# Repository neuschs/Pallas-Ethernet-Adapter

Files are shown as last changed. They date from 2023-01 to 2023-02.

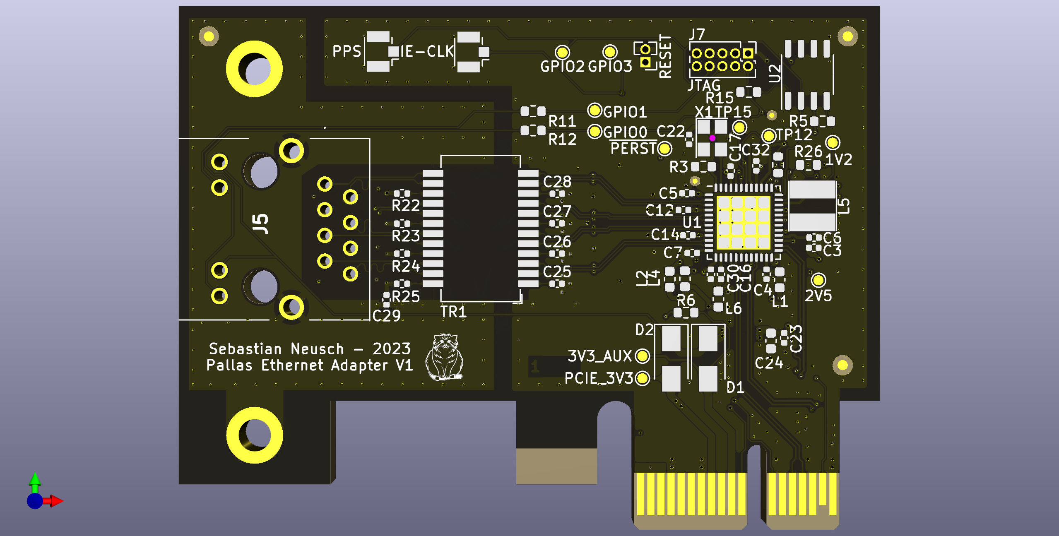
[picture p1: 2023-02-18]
documentation/pallas-ethernet-adapter_top.png

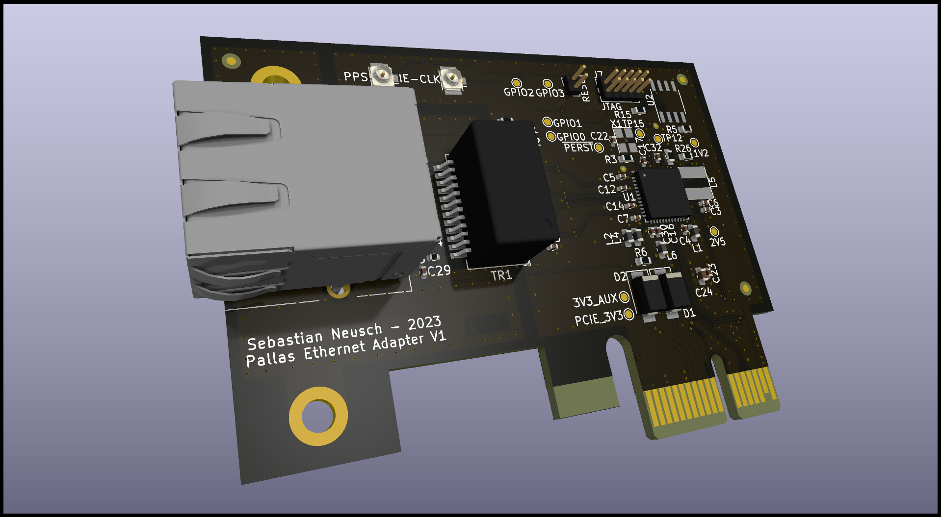
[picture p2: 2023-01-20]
documentation/pallas-ethernet-adapter.png

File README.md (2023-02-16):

# Pallas-Ethernet-Adapter
Open source PCIe ethernet adapter based on LAN7430

More information can be found on my blog: https://sebis-workshop.de/uncategorized/pallas-ethernet-adapter/

# Ordering and production parameters
So far I've just ordered the PCBAs and waiting to test my prototypes.
In the folder jlcpcb are the files from this KiCAD plugin located:
https://github.com/Bouni/kicad-jlcpcb-tools

Including position correction for some parts so the pick'n'place file is correct (please check before usage).

# Credits
Thanks to the KiCAD PCIe template project:
https://github.com/lucanastasio/PCIexpress-KiCad

# License
All datasheets are just for documentational pruposes here. All credits go to the companys which distributed them initially.

The Logo - the Pallas Cat - may not be redistributed, made public elsewhere or modified and is property of the author. 

This describes Open Hardware and is licensed under the CERN OHL v.1.2.
You may redistribute and modify this under the terms of the CERN OHL v.1.2. (http://ohwr.org/cernohl). This is distributed WITHOUT ANY EXPRESS OR IMPLIED WARRANTY, INCLUDING OF MERCHANTABILITY, SATISFACTORY QUALITY AND FITNESS FOR A PARTICULAR PURPOSE. Please see the CERN OHL v.1.2 for applicable conditions.

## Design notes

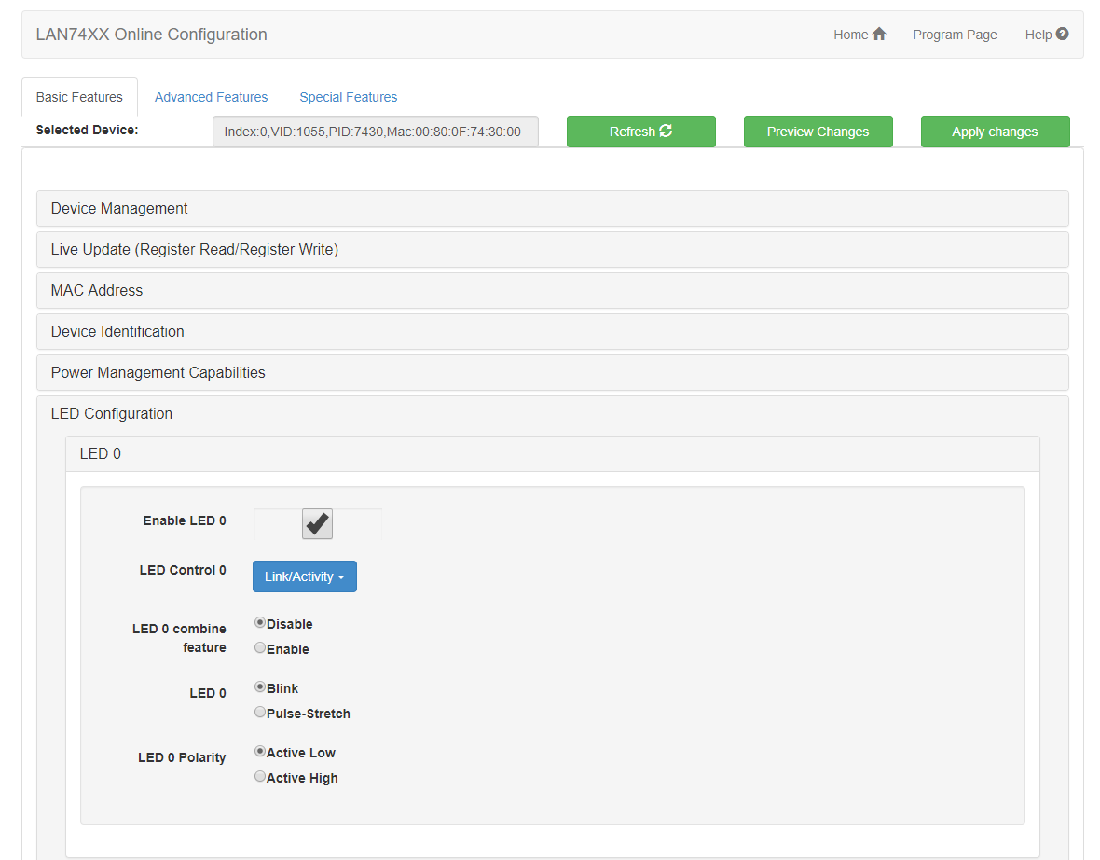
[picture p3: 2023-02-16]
documentation/configuration_example.png

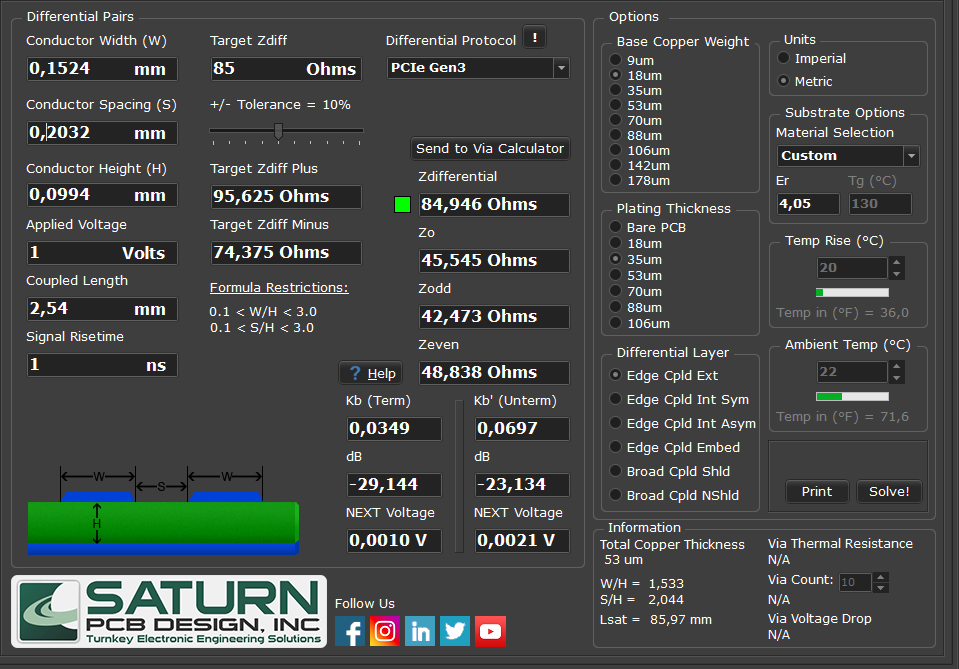
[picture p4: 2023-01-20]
documentation/pcie-tracks-impedance.png

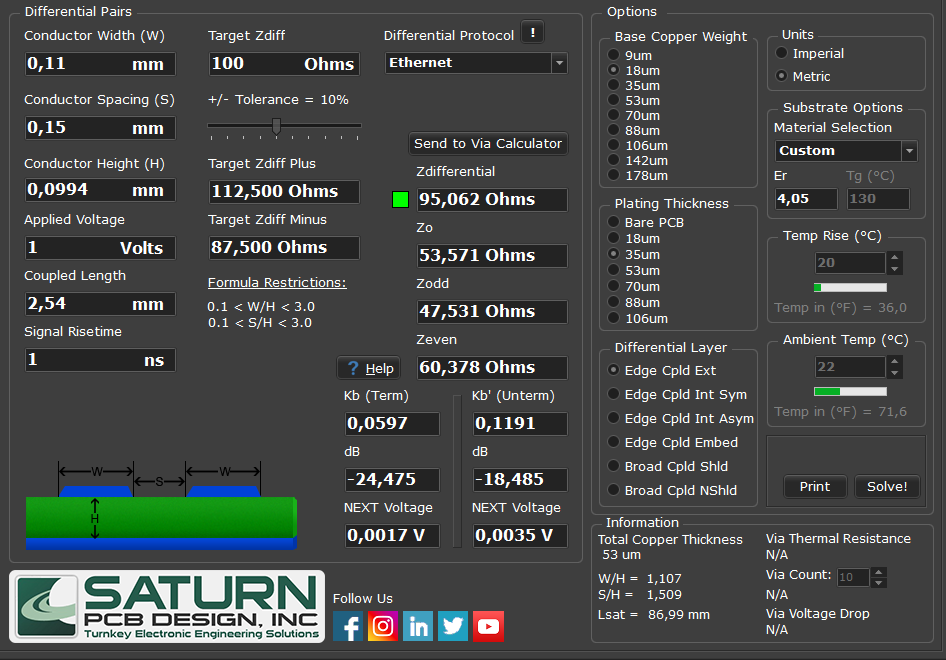
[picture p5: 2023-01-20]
documentation/ethernet-tracks-impedance.png

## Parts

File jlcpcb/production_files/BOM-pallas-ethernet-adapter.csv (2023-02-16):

Comment | Designator | Footprint | LCSC
93AAxxA | U2 | SO-8_3.9x4.9mm_P1.27mm | C153277
0 | R15,R20 | R_0603_1608Metric | C21189
1k | R5 | R_0603_1608Metric | C21190
330 | R11,R12,R6 | R_0603_1608Metric | C23138
4.7uF | C3,C8 | C_0402_1005Metric | C23733
SS14 | D1,D2 | D_SMA | C2480
75 | R22,R23,R24,R25 | R_0402_1005Metric | C25133
10k | R26 | R_0603_1608Metric | C25804
3.3uH | L5 | L_CY43-3.3UH | C2929417
25 MHz | X1 | OXETGLJANF-25MHZ_FPN | C295525
100n | C1,C11,C12,C14,C15,C16,C17,C18,C19,C2,C22,C23,C25,C26,C27,C28,C29,C30,C31,C32,C4,C5,C6,C7,C9 | C_0402_1005Metric | C307331
6.04k | R3 | R_0603_1608Metric | C325745
SRV05-4 | U3,U4 | SOT-23-6 | C397788
MT24-S1T1 | TR1 | Transformer_Ethernet_HALO_TG111-MSC13 | C501477
1uF | C10 | C_0402_1005Metric | C52923
LAN7430 | U1 | QFN-48-1EP_7x7mm_P0.5mm_EP5.3x5.3mm | C633486
200 | R4 | R_0603_1608Metric | C8218
PPS | J3,J4 | U.FL_Hirose_U.FL-R-SMT-1_Vertical | C88373
220R | L1,L2,L3,L4,L6,L7,L8 | L_0603_1608Metric | C88971
10uF | C13,C24 | C_0603_1608Metric | C96446
PCIexpress_bracket | J1 | PCIexpress_bracket_low
RESET | J6 | PinHeader_1x02_P1.27mm_Vertical
JTAG | J7 | PinHeader_2x05_P1.27mm_Vertical
RJ45_LED_Shielded | J5 | SS74800038F

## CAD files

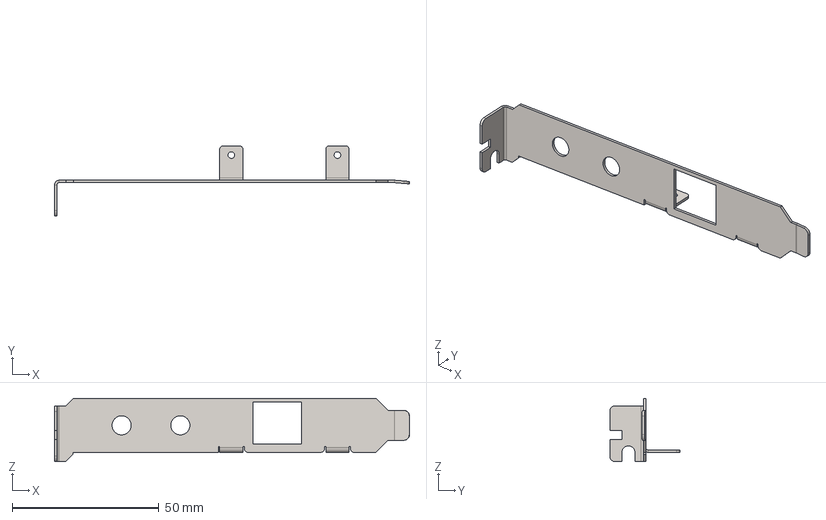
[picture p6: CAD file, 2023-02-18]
pcie-bracket/PCIexpress_bracket_full v2.step
120.9 x 24.0 x 21.6 mm

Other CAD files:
pcie-bracket/PCIexpress_bracket_full v2.stl

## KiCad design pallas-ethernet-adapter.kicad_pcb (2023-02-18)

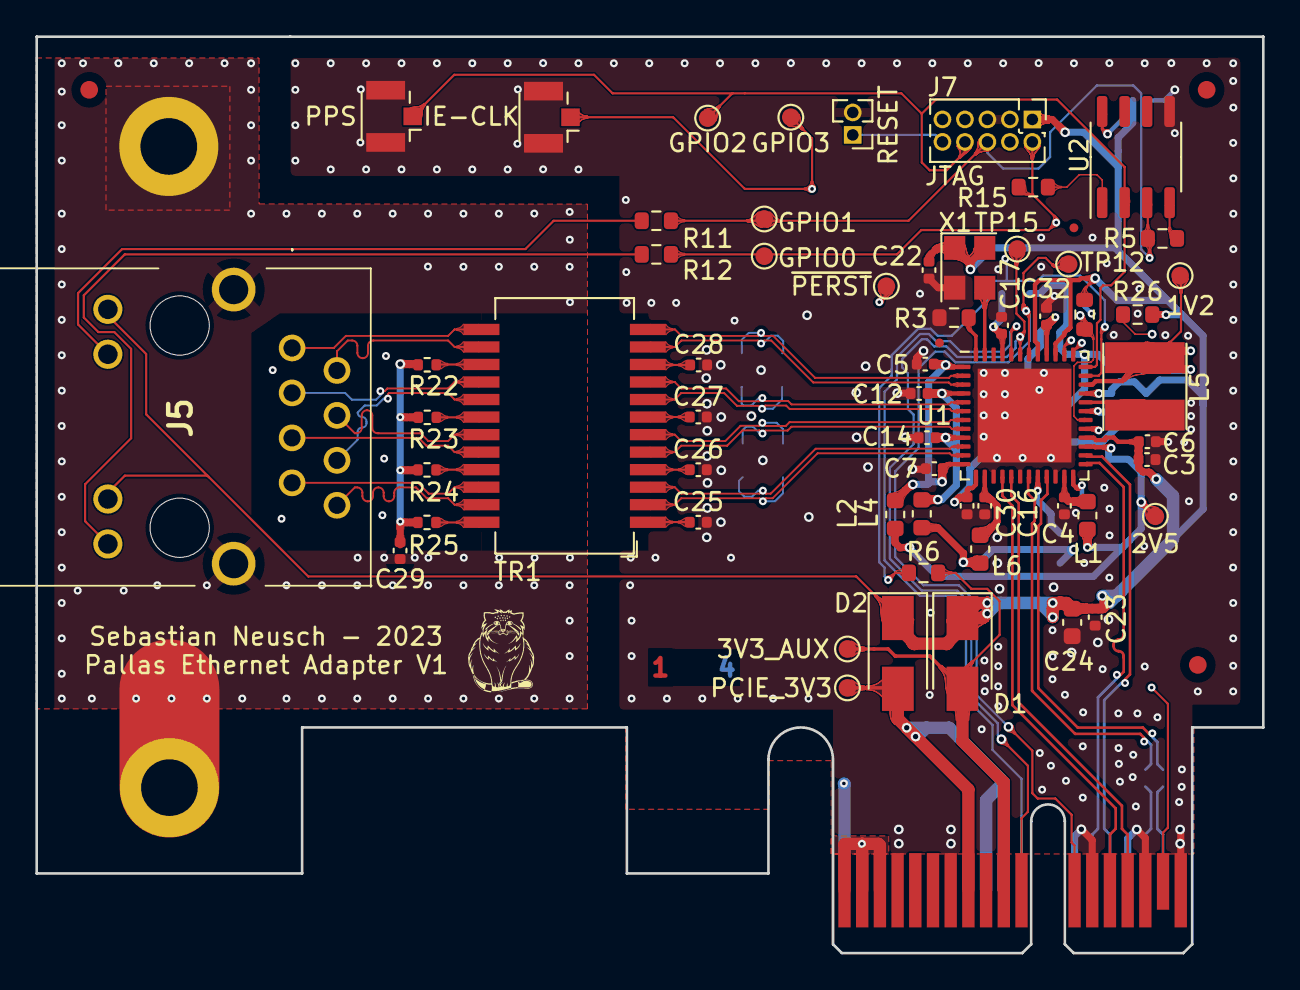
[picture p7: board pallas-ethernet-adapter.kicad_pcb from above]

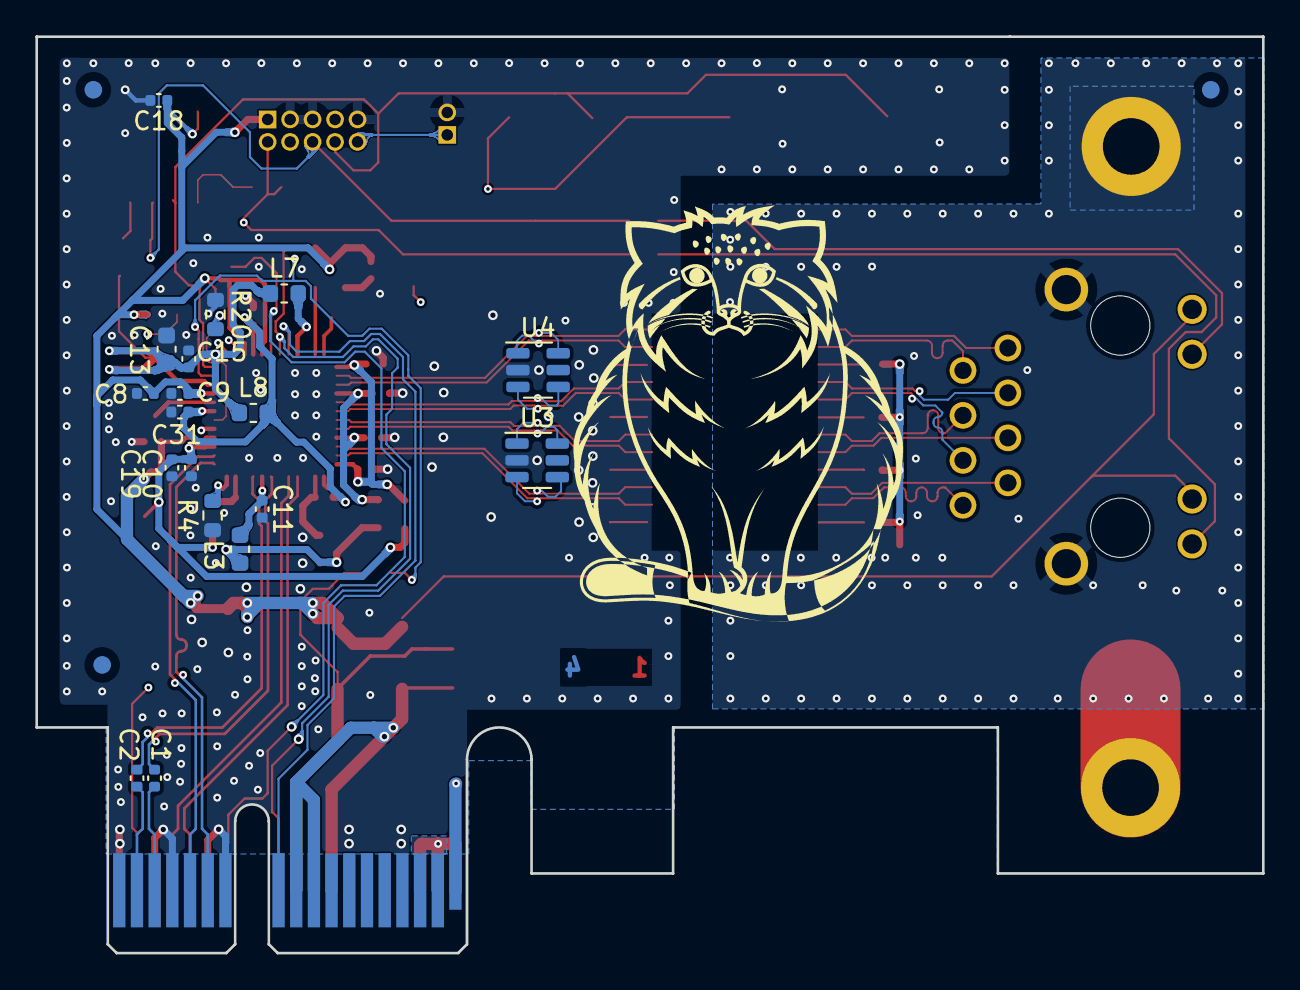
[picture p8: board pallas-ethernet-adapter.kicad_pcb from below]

Board: 4 copper layers, 69.3 x 51.8 mm, 88 parts (21 on the bottom side), 66 nets.

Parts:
C1, C2: 100n; C_0402_1005Metric
C3, C8: 4.7uF; C_0402_1005Metric
C4, C5, C6, C7, C9, C11, C12, C14, C15, C16, C17, C18, C19, C22, C23, C25, C26, C27, C28, C29, C30, C31, C32: 100nF; C_0402_1005Metric
C10: 1uF; C_0402_1005Metric
C13, C24: 10uF; C_0603_1608Metric
D1, D2: SS14; D_SMA
FID1, FID2, FID3, FID4, FID5, FID6: Fiducial; Fiducial_1mm_Mask2mm
FID7, FID8: Fiducial; Fiducial_0.5mm_Mask1mm
H1, H2: PCIE_Bracket_Hole; MountingHole_3.2mm_M3_DIN965_Pad
J1: PCIexpress_bracket; PCIexpress_bracket_low
J2: PCIexpress_x1
J3: PPS; U.FL_Hirose_U.FL-R-SMT-1_Vertical
J4: IE-CLK; U.FL_Hirose_U.FL-R-SMT-1_Vertical
J5: RJ45_LED_Shielded; SS74800038F
J6: RESET; PinHeader_1x02_P1.27mm_Vertical
J7: JTAG; PinHeader_2x05_P1.27mm_Vertical
L1, L2, L3, L4, L6, L7, L8: 220R; L_0603_1608Metric
L5: 3.3uH; L_CY43-3.3UH
R3: 6.04k; R_0603_1608Metric
R4: 200; R_0603_1608Metric
R5: 1k; R_0603_1608Metric
R6, R11, R12: 330; R_0603_1608Metric
R15, R19, R20: 0; R_0603_1608Metric
R22, R23, R24, R25: 75; R_0402_1005Metric
R26: 10k; R_0603_1608Metric
TP1: 2V5; TestPoint_Pad_D1.0mm
TP2: 1V2; TestPoint_Pad_D1.0mm
TP3: GPIO3; TestPoint_Pad_D1.0mm
TP4: GPIO2; TestPoint_Pad_D1.0mm
TP5: GPIO1; TestPoint_Pad_D1.0mm
TP6: GPIO0; TestPoint_Pad_D1.0mm
TP10: PCIE_3V3; TestPoint_Pad_D1.0mm
TP12: ~{CLKREQ}; TestPoint_Pad_D1.0mm
TP13: ~{PERST}; TestPoint_Pad_D1.0mm
TP14: 3V3_AUX; TestPoint_Pad_D1.0mm
TP15: ~{WAKE}; TestPoint_Pad_D1.0mm
TR1: MT24-S1T1; Transformer_Ethernet_HALO_TG111-MSC13
U1: LAN7430; QFN-48-1EP_7x7mm_P0.5mm_EP5.3x5.3mm
U2: 93AAxxA; SO-8_3.9x4.9mm_P1.27mm
U3, U4: SRV05-4; SOT-23-6
X1: 25 MHz; OXETGLJANF-25MHZ_FPN

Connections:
+3V3: C3.1, C6.1, C8.1, C9.1, C18.1, C22.1, C23.1, C24.1, D1.1 (K), D2.1 (K), J5.10, J5.12, J7.1 (VTref), R19.2, R26.1, U1.28 (VDD_REG_IN), U1.33 (VDD_SW_IN), U1.39 (VDDVARIO), U1.41 (VDD_OTP), U2.8 (VCC), X1.1 (EN), X1.4 (Vdd)
/CASE: C29.2, H1.1, H2.1, J5.SH
/Ethernet/BOB_SMITH: C29.1, R22.2, R23.2, R24.2, R25.2
/Ethernet/MDI_A_CT: R22.1, TR1.15 (MCT4)
/Ethernet/MDI_A_N: J5.2, TR1.14 (MX4+)
/Ethernet/MDI_A_P: J5.1, TR1.13 (MX4-)
/Ethernet/MDI_B_CT: R23.1, TR1.18 (MCT3)
/Ethernet/MDI_B_N: J5.6, TR1.17 (MTX3+)
/Ethernet/MDI_B_P: J5.3, TR1.16 (MTX3-)
/Ethernet/MDI_C_CT: R24.1, TR1.21 (MCT2)
/Ethernet/MDI_C_N: J5.5, TR1.20 (MTX2+)
/Ethernet/MDI_C_P: J5.4, TR1.19 (MTX2-)
/Ethernet/MDI_D_CT: R25.1, TR1.24 (MTC1)
/Ethernet/MDI_D_N: J5.8, TR1.23 (MTX1+)
/Ethernet/MDI_D_P: J5.7, TR1.22 (MTX1-)
/Ethernet/TXRX_A_CT: C28.1, TR1.10 (TCT4)
/Ethernet/TXRX_A_N: TR1.11 (TD4+), U1.3 (TXRXM_A), U4.1 (I/O1)
/Ethernet/TXRX_A_P: TR1.12 (TD4-), U1.2 (TXRXP_A), U4.6 (I/O4)
/Ethernet/TXRX_B_CT: C27.1, TR1.7 (TCT3)
/Ethernet/TXRX_B_N: TR1.8 (TD3+), U1.6 (TXRXM_B), U4.3 (I/O2)
/Ethernet/TXRX_B_P: TR1.9 (TD3-), U1.5 (TXRXP_B), U4.4 (I/O3)
/Ethernet/TXRX_C_CT: C26.1, TR1.4 (TCT2)
/Ethernet/TXRX_C_N: TR1.5 (TD2+), U1.8 (TXRXM_C), U3.6 (I/O4)
/Ethernet/TXRX_C_P: TR1.6 (TD2-), U1.7 (TXRXP_C), U3.1 (I/O1)
/Ethernet/TXRX_D_CT: C25.1, TR1.1 (TCT1)
/Ethernet/TXRX_D_N: TR1.2 (TD1+), U1.11 (TXRXM_D), U3.3 (I/O2)
/Ethernet/TXRX_D_P: TR1.3 (TD1-), U1.10 (TXRXP_D), U3.4 (I/O3)
/LAN7430/AVDD12: C17.1, L7.2, U1.45 (AVDD12)
/LAN7430/AVDDH: C5.1, C7.1, L2.2, U1.1 (AVDDH_1), U1.12 (AVDDH_2)
/LAN7430/AVDDL: C12.1, C14.1, L4.2, U1.4 (AVDDL_1), U1.9 (AVDDL_2)
/LAN7430/CS: R15.2, U2.1 (CS)
/LAN7430/ISET: R3.2, U1.48 (ISET)
/LAN7430/OSC_OUT: U1.47 (XI), X1.3 (OUT)
/LAN7430/PCIE_CLK_N: J2.A14 (REFCLK-), U1.26 (PCIE_CLK_M)
/LAN7430/PCIE_CLK_P: J2.A13 (REFCLK+), U1.25 (PCIE_CLK_P)
/LAN7430/PCIE_RX_N: J2.B15 (PET0-), U1.17 (PCIE_RX_M)
/LAN7430/PCIE_RX_P: J2.B14 (PET0+), U1.16 (PCIE_RX_P)
/LAN7430/PCIE_TX_N: C2.2, U1.21 (PCIE_TX_M)
/LAN7430/PCIE_TX_P: C1.1, U1.19 (PCIE_TX_P)
/LAN7430/PCIE_VAUX_DET: D1.2 (A), J2.B10 (+3.3V_aux), R6.2, TP14.1
/LAN7430/RESREF: R4.2, U1.24 (RESREF)
/LAN7430/SDO: R5.1, U2.4 (DO)
/LAN7430/TEST: R19.1, R20.2, U1.30 (TEST)
/LAN7430/VDD12CORE: C30.1, C31.1, C32.1, L8.2, U1.13 (VDD12CORE), U1.31 (VDD12CORE), U1.40 (VDD12CORE)
/LAN7430/VDD12_SW_FB: C13.1, C15.1, L3.1, L4.1, L5.2, L6.1, L7.1, L8.1, TP2.1, U1.34 (VDD12_SW_FB)
/LAN7430/VDD12_SW_OUT: L5.1, U1.32 (VDD12_SW_OUT)
/LAN7430/VDD_2V5: C10.1, C19.1, L1.1, L2.1, TP1.1, U1.27 (VDD25_REG_OUT)
/LAN7430/VP: C16.1, L6.2, U1.14 (VP)
/LAN7430/VPH: C4.1, L1.2, U1.23 (VPH)
/LAN7430/VPTX: C11.1, L3.2, U1.20 (VPTX)
/LAN7430/~PCIE_CLKREQ: J2.B12 (nCLKREQ), TP12.1, U1.42 (CLKREQ#)
/LAN7430/~PCIE_PERST: J2.A11 (~PERST), TP13.1, U1.44 (PERST#)
/LAN7430/~PCIE_WAKE: J2.B11 (~WAKE), TP15.1, U1.43 (WAKE#)
/LAN_JTAG_TCK: J4.1 (In), J7.4 (TCK), R6.1, TP3.1, U1.35 (VAUX_DET/GPIO3/LED3/TCK)
/LAN_JTAG_TDI: J7.2 (TMS), R12.1, R15.1, TP6.1, U1.38 (EECS/GPIO0/LED0/TDI)
/LAN_JTAG_TDO: J7.6 (TDO), R5.2, R11.1, TP5.1, U1.37 (EEDIO/GPIO1/LED1/TDO), U2.3 (DI)
/LAN_JTAG_TMS: J3.1 (In), J7.8 (TDI), TP4.1, U1.36 (EECLK/GPIO2/LED2/TMS/ADV_PM_DISABLE), U2.2 (SCLK)
/PCIexpress_connector/3V3: D2.2 (A), J2.A9 (+3.3V), J2.A10 (+3.3V), J2.B8 (+3.3V), TP10.1
/PCIexpress_connector/12V: J2.A2 (+12V), J2.A3 (+12V), J2.B1 (+12V), J2.B2 (+12V), J2.B3 (+12V)
/PCIexpress_connector/_PER0_N: C2.1, J2.A17 (PERn0)
/PCIexpress_connector/_PER0_P: C1.2, J2.A16 (PERp0)
/PCIexpress_connector/~PRSNT1: J2.A1 (~PRSNT1), J2.B17 (~PRSNT2)
/RESET: J6.1, J7.10 (~RESET), R26.2, U1.29 (RESET_N)
/~LED0: J5.11, R12.2
/~LED1: J5.9, R11.2
GND: C3.2, C4.2, C5.2, C6.2, C7.2, C8.2, C9.2, C10.2, C11.2, C12.2, C13.2, C14.2, C15.2, C16.2, C17.2, C18.2, C19.2, C22.2, C23.2, C24.2, C25.2, C26.2, C27.2, C28.2, C30.2, C31.2, C32.2, J2.A4 (GND), J2.A12 (GND), J2.A15 (GND), J2.A18 (GND), J2.B4 (GND), J2.B7 (GND), J2.B13 (GND), J2.B16 (GND), J2.B18 (GND), J3.2 (Ext), J4.2 (Ext), J6.2, J7.3 (GND), J7.5 (GND), J7.9 (GNDDet), R3.1, R4.1, R20.1, U1.15 (GD_1), U1.18 (GD_2), U1.22 (GD_3), U1.49 (EPAD), U2.5 (GND), U3.2 (GND), U4.2 (GND), X1.2 (GND)

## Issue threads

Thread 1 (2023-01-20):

Increase magnetics<-->phy distance for better EMI performance

neuschs, 2023-01-20:

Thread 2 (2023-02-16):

Remove R19 from BOM / CPL

neuschs, 2023-02-16:
Resistor was in the bill of material even though the resistor shouldn't have been populated. Causing a short curcuit between VCC 3V3 and GND.

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

Closed 2023-02-16.

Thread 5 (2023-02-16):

Hole siye for RJ45 connector to small

neuschs, 2023-02-16:
The mechanical mounting holes for SS74800-132F were a little to small and needed more force than advisible.

neuschs, 2023-02-18:
This commit didn't solved the issue

Closed 2023-02-18.

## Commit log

2023-01-17 really added all the files not like last time
    [PCIexpress_connector.kicad_sch, PCIexpress_connector.sch, decap.kicad_sch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]
2023-01-19 * ground plane change to keep out beneath the magnetic module * changed RJ45 modular jack from tab up to tab down to improve the routing * added an 3d modell in the library folder for the rj45 connec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
    [ethernet.kicad_sch, pallas-ethernet-adapter.kicad_pcb, pallas-ethernet-adapter.kicad_sch]
2023-01-20 * moved magnetics to RJ45 connector for better EMI performance (still not enough though) * changed keepout layer beneath magnetics * moved meanders from magnetic side to connector side (from matched 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
    [pallas-ethernet-adapter.kicad_pcb]
2023-01-20 * corrected some drc errors like hole clearance, unconnected tracks etc.. * added screenshots of the impedance calculation in regards of the JLCPCB 3313 stackup * added picture of rendered 3d perspec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
    [pallas-ethernet-adapter.kicad_pcb]
2023-01-20 * changed license to exclude the pallas cat logo * added the logo to the pcb as front and back silkscreen
    [pallas-ethernet-adapter.kicad_pcb]
2023-01-20 * corrected angle data in the jlcpcb plugin data * generated near final gerber files - waiting for release by a peer partner
    [pallas-ethernet-adapter-CuBottom.gbr, pallas-ethernet-adapter-CuIn1.gbr, pallas-ethernet-adapter-CuIn2.gbr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]
2023-01-29 * generated production files new * added bom and cpl pick and place file (previous not included)
    [BOM-pallas-ethernet-adapter.csv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]
2023-02-16 * removed R19 from jlcpcb CPL (PNP File) and from BOM fix: #2 * widened the holes for the RH45 connector by 0.1mm fix: #5 * added datasheets to documentation directory as well as a dummy graphic for 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
    [BOM-pallas-ethernet-adapter.csv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]
2023-02-16 * repoured all copper zones and reexported production files to accomodate last changes
    [pallas-ethernet-adapter-CuBottom.gbr, pallas-ethernet-adapter-CuIn1.gbr, pallas-ethernet-adapter-CuIn2.gbr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]
2023-02-16 * created initial configuration file with the two LEDs * LED0 & LED1 activated as Link/Activity and Link1000/Activity * deactivated EnergySave Power Mode * ATTENTION the eeprom-dump.bin file contains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
2023-02-18 * added bracket in stl and step format fix: #4 * fixed hole size of rj45 finally fix: #5
    [PCIexpress_bracket_full v2.step, PCIexpress_bracket_full v2.stl, pallas-ethernet-adapter.kicad_pcb]
2023-02-18 * created manufacuring files for past changes
    [pallas-ethernet-adapter-CuBottom.gbr, pallas-ethernet-adapter-CuIn1.gbr, pallas-ethernet-adapter-CuIn2.gbr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]
